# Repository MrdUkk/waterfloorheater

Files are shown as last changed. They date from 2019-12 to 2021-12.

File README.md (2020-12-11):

# water floor heater system

Complete and ready-to-use WiFi-enabled water floors heating system with remote sensors and 
controllers over 1-wire (One Wire) interface.

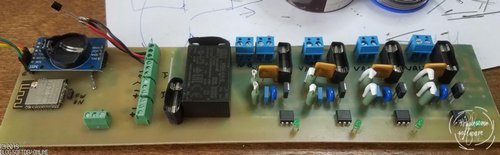
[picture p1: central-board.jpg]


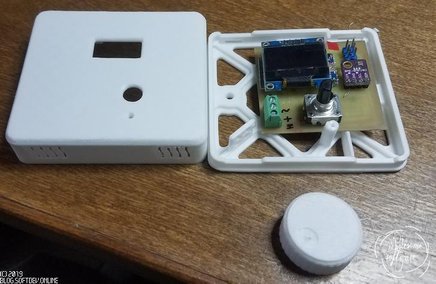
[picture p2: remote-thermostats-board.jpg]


Uses: 
1. OLED 0.96" display (no-name China), 
2. ESP32 (as central controller),
3. ATMEGA328 (as slave remote thermostats placed on rooms walls).
4. BME280 sensors
5. TRIACs (for opening/closing water valve actuators)

Full assembly instructions with photos and detailed description (written currently into Russian lang):
Part1 (hardware): https://blog.softdev.online/index.php?controller=post&action=view&id_post=10

Part2 (software): https://blog.softdev.online/index.php?controller=post&action=view&id_post=11

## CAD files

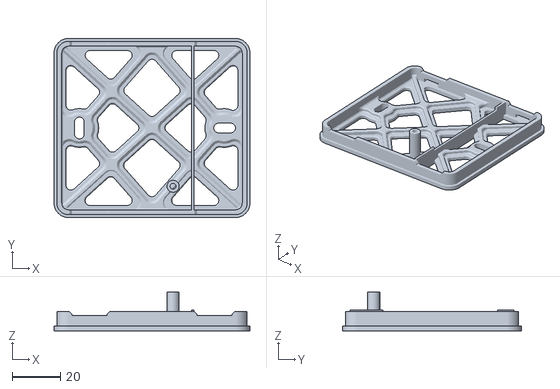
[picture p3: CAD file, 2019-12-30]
3d-shell/bottom.stl
81.0 x 74.0 x 16.0

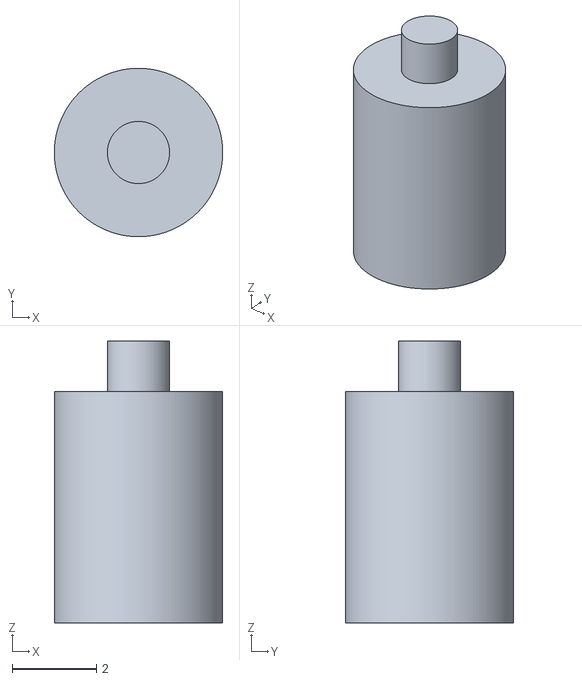
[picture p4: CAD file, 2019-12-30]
3d-shell/display-legs.stl
4.00 x 4.00 x 6.70

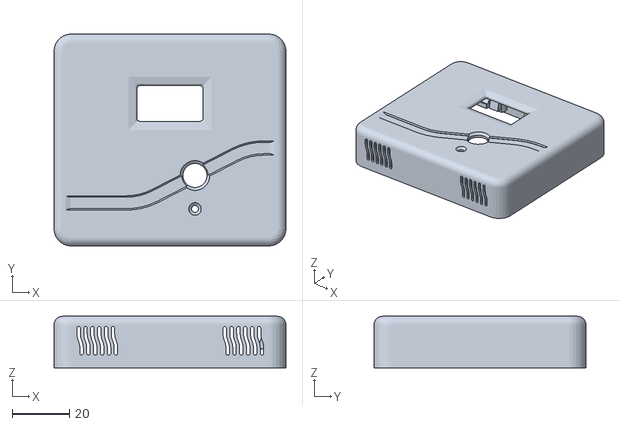
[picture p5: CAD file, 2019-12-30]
3d-shell/top.stl
81.0 x 74.0 x 18.0

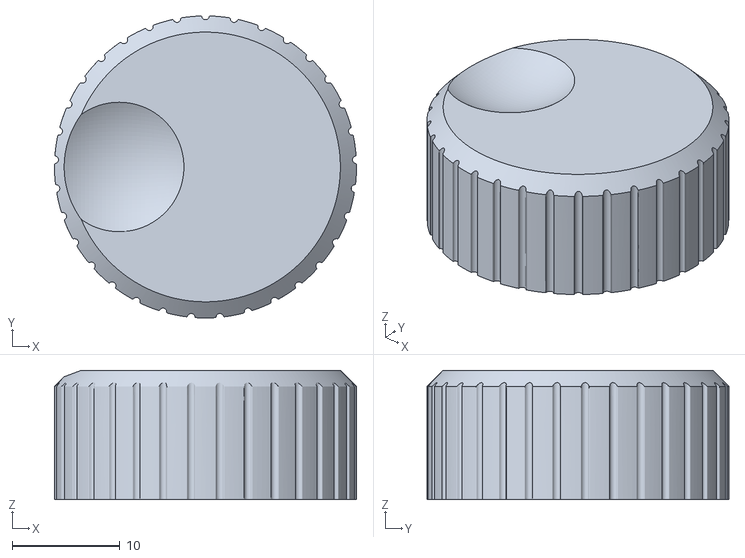
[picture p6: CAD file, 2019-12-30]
3d-shell/jog.stl
28.0 x 28.0 x 12.0

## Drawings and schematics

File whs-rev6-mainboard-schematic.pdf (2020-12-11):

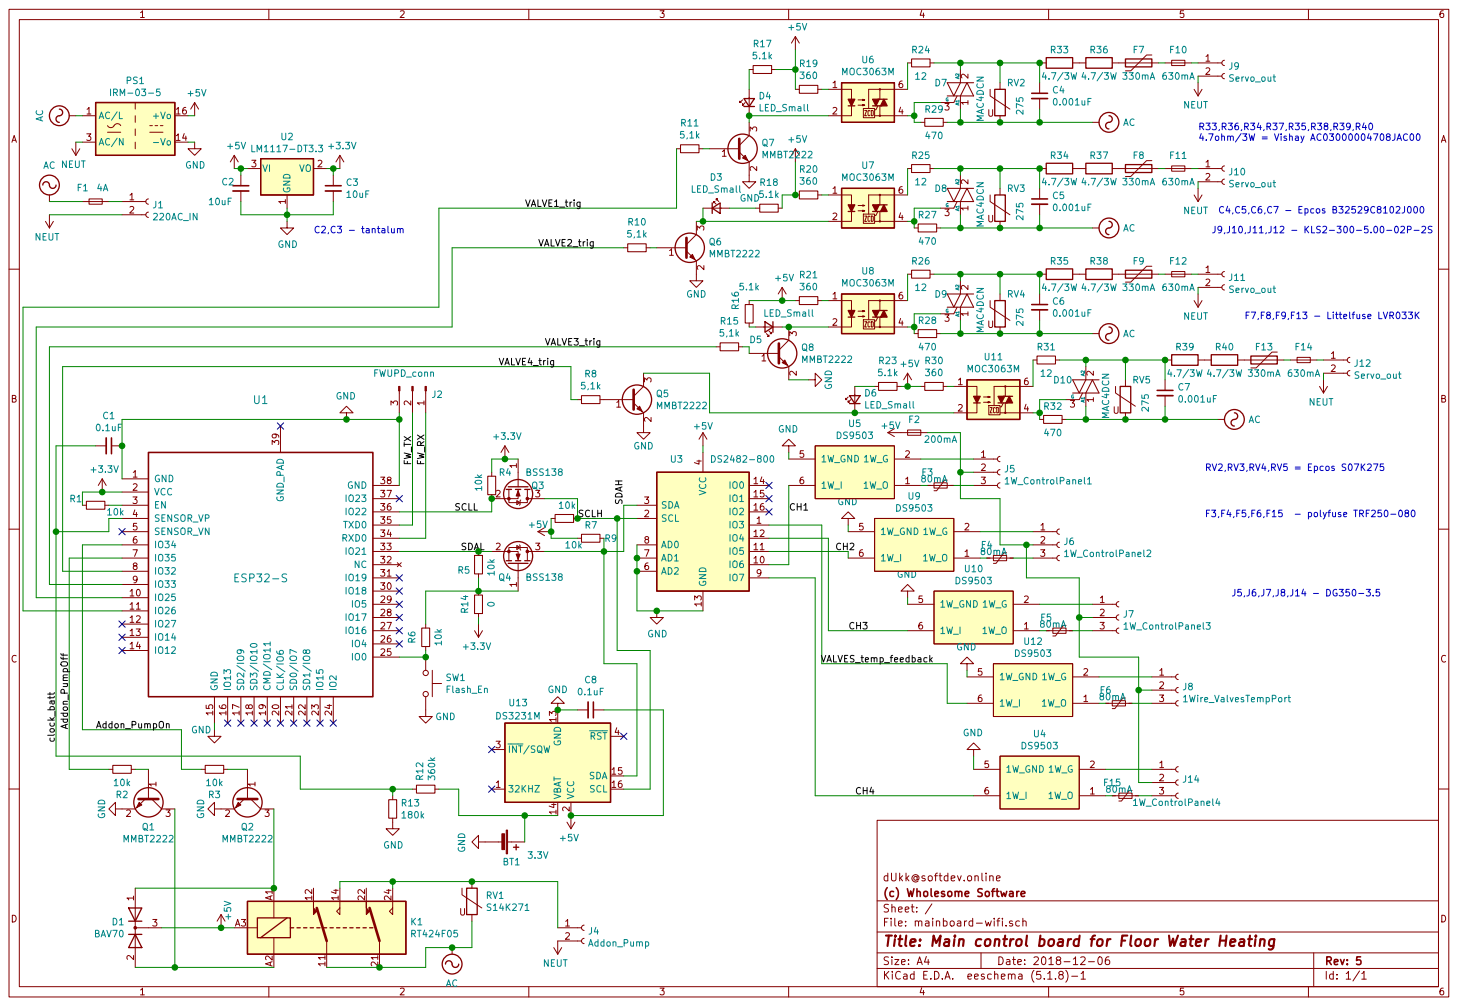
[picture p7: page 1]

File: mainboard-wifi.sch Sheet: / (c) Wholesome Software

Id: 1/1 Title: Main control board for Floor Water Heating

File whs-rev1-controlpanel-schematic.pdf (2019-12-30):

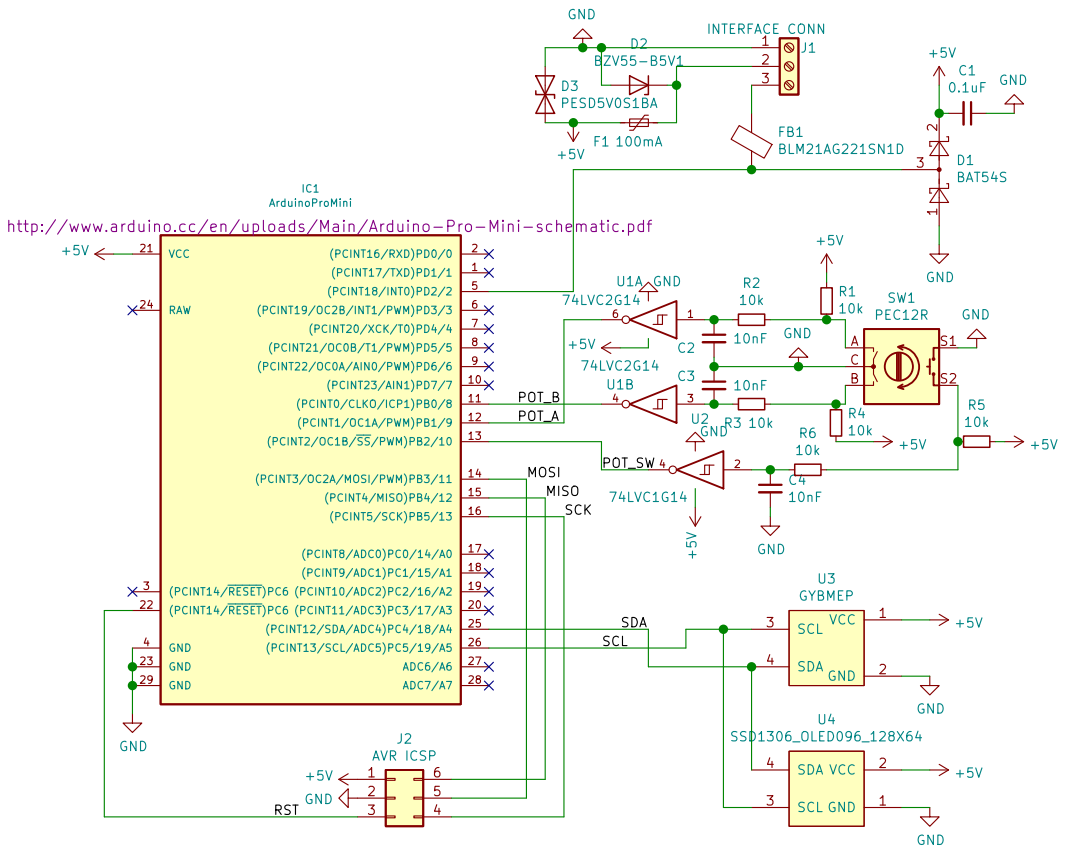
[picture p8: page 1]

File: controlpanel.sch Sheet: / Wholesome Software

Id: 1/1 Title: Control panel board for Smart Floor Heating

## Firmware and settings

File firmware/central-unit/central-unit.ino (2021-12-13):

/*
   Waterfloors Heating System (WHS)
   - main module firmware (ESP32-S microcontroller with DS8242 + DS3231)

  tested on: ArduinoIDE v1.8.15 + ESP32 Dev Module (CPU Freq 160mhz). SDK was v2.0.0


v2.0 (2021-12-13)
+fix bugs in DS2482 code
+introduce checking status of correct settings push to remote panels (in case of error will continue push)
+remove unneeded scratchpad read before pushing remote panel config (speedup)
+restored maintenance cycle in case valve is not used last X days
+added new heatin mode: duty cycle (cycling on->off mode every X seconds)
+added active-pullup mode by default ON on 1W bus
+fix multi-timezone temperature bug


   Written by dUkk (c) 2018-2021 Wholesome Software
*/

#include <Wire.h>
#include <EEPROM.h>
#include <WiFi.h>
#include <HTTPClient.h>
#include <rom/rtc.h>
#include <driver/rtc_io.h>
#include <driver/adc.h>
#include <RtcDS3231.h>
#include "MYDS2482.h"
#include "OWRemoteDevices.h"
#include "PIDLib.h"

#define DEBUG 1

#define RTCTS_OFFSET 946684800 //we get time from server at base year 1970, but here we counting from 2000

#define NO_ADDR_ASSIGNED 255

#define HEATER_MODE_OFF 0
#define HEATER_MODE_PIDTUNE 1
#define HEATER_MODE_PID_SINGLEZONE 2
#define HEATER_MODE_PID_MULTIZONE 3
#define HEATER_MODE_DUTYCYCLE 4

#define SSID_NAME "bssid"
#define SSID_PASSWORD "wifipassword"
#define HTTP_HOST "serverhost.name"
#define OUR_HOSTNAME "wfh"

#define RUNCYCLE_FREQ 20 //panels and sensors data grab cycle and PID compute cycle will run at this interval (in seconds)
#define VALVE_PWM_CYCLES 6 //TRIAC opening or closing valve window. VALVE_PWM_CYCLES*RUNCYCLE_FREQ (in seconds)
#define VALVE_INACTIVE_MAX_SECONDS 345600  //this is maximum valve inactive state in seconds before we start 15minutes cycle opening and closing it
#define VALVE_MAINTENANCE_SECONDS 900 //how long valve should be opened in case of its inactive state

RtcDS3231<TwoWire> Rtc(Wire);
//1wire switch instance  0 = 0x18 address
MYDS2482 OWSwitch(0);
OWRemoteDevices OneWireBus(&OWSwitch);

RTC_DATA_ATTR uint32_t nextTimeConnect, NextRunCycleTS;
bool first_time;

struct HEATER_PANEL {
  //PID coeff
  double Kp;
  double Ki;
  double Kd;
  //manual corrections of humidity and temperature
  float toffset;
  int8_t hoffset;
  //1Wire addresses for panel and associated termometr (mounted on pipe)
  int32_t PanelAddress;
  int32_t TermalSensorAddress;
  //current channel operation mode
  uint8_t CurrentMode;   //(0= OFF, 1= PID calibration, 2= single temperature every hour, 3= three time ranges distinct temperatures
  //for 3-timezones mode (individual zone ranges and temperature)
  int32_t TZoneStart[3];
  int32_t TZoneEnd[3];
  //user setted temperature. 0..2 is for multi timezone
  double TZoneDesiredTemp[3];
  //for fixed everytime tempepature
  double desiredTemp;
  //for Hysteresis type control
  uint32_t DutyCyclesMax;
};

struct {
  //for PID
  double input;
  double output;
  //forward pipe flow temperature sensor value
  float ValveTemp;
  //room humidity from remote unit
  uint8_t humidity;
  //number of
  uint32_t OnTimeCount;
  uint16_t PanelErrorsOnBus;
  uint16_t SensorErrorsOnBus;
  uint32_t PanellastOnline;
  uint32_t SensorlastOnline;
  uint32_t NumberOfCycles;
  uint32_t LastuseTS;
  //GPIO pin number of ESP32
  uint8_t Pin;
  //this holds pointer (to HEATER_PANEL[n].) to not recalculate N-times current selected temperature
  double *ptrToCurSettemp;
  //flag to send autotune calibration data to server
  bool PIDTuneReady;
  //flag to push current config to remote panel
  bool NeedPushConfig;
} RunningValues[4];

struct MY_SETTINGS {
  uint16_t crc16;
  int32_t ConnInterval;
  wifi_power_t txpower;
  char ssid[16];
  char password[32];
  HEATER_PANEL HeaterConfig[4];
} settings;

struct rtcData_WIFI {
  uint16_t crc16;   // 2 bytes
  uint8_t channel;  // 1 byte,   3 in total
  uint8_t bssid[6]; // 6 bytes,  9 in total
  uint8_t padding;  // 1 byte,  10 in total
};

RTC_DATA_ATTR rtcData_WIFI rtcData;

PID PIDHeaterMachinery[4];

unsigned int CRC16(unsigned char *buf, int len);
String extractParam(const String &authReq, const String &param);
bool is_between(const int32_t value, const int32_t rangestart, const int32_t rangeend);
void ParseServerResponse(String &payload, String &value);
uint8_t GetDeviceIndex(const int32_t HWAddress);
bool AssignProperSetTemp(uint8_t PanelIdx, uint32_t CurTime);
void SpinPIDHeatersCycle(uint32_t CurTS);
void UpdateHeatersLastuse(uint32_t TS);
bool PushToControlPanel(uint8_t PanelIdx, uint8_t deviceIdx);
void ScanOWBus();
void saveSettings();
void loadSettings();
bool InitiateWIFI();
void ShutdownWIFI();
float getVBatt();

void setup()
{
#ifdef DEBUG
  Serial.begin(115200);
  delay(10);
  Serial.printf("our settings struct size: %d , I2C: SDA=%d SCL=%d\r\n", sizeof(settings), SDA, SCL);
#endif
  EEPROM.begin(sizeof(settings));

#ifdef DEBUG
  byte error, address;
  Serial.printf("I2C init=%d\r\n",  Wire.begin(SDA, SCL));
  for(address = 1; address < 127; address++ )
  {
    Wire.beginTransmission(address);
    error = Wire.endTransmission();
    if (error == 0)
    {
      Serial.print("I2C device found at address 0x");
      if (address<16)
        Serial.print("0");
      Serial.print(address,HEX);
      Serial.println("  !");
    }
  }
#else
  Wire.begin(SDA, SCL);
#endif

  pinMode(26, OUTPUT); //GPIO26 = valve1
  pinMode(25, OUTPUT); //GPIO25 = valve2
  pinMode(33, OUTPUT); //GPIO33 = valve3
  pinMode(32, OUTPUT); //GPIO32 = valve4
  pinMode(35, OUTPUT); //GPIO35 = Pump relay off
  pinMode(34, OUTPUT); //GPIO34 = Pump relay on

  digitalWrite(26, LOW); //Initial state
  digitalWrite(25, LOW); //Initial state
  digitalWrite(33, LOW); //Initial state
  digitalWrite(32, LOW); //Initial state
  digitalWrite(35, LOW); //Initial state
  digitalWrite(34, LOW); //Initial state

  loadSettings();
  WiFi.persistent(false);
  WiFi.setAutoConnect(false);
  WiFi.setAutoReconnect(false);
  WiFi.mode(WIFI_OFF);
  btStop();

  if (!Rtc.IsDateTimeValid())
  {
#ifdef DEBUG
    Serial.print("RTC invalid TS, resetting it\n");
#endif
      RtcDateTime compiled = RtcDateTime(__DATE__, __TIME__);
      Rtc.SetDateTime(compiled);
  }

  if (!Rtc.GetIsRunning())
  {
#ifdef DEBUG
    Serial.println("RTC not running, starting\n");
#endif
    Rtc.SetIsRunning(true);
  }
#ifdef DEBUG
  else
    Serial.print("RTC already running\n");
#endif
  Rtc.Enable32kHzPin(false);
  Rtc.SetSquareWavePin(DS3231SquareWavePin_ModeNone);

#ifdef DEBUG
  Serial.printf("1W switch reset %d\n", OWSwitch.reset());
  Serial.printf("1W switch APU %d\n", OWSwitch.configure(DS2482_CONFIG_APU));
#else
  OWSwitch.reset();
  OWSwitch.configure(DS2482_CONFIG_APU);
#endif

  //wait until all remote control panels is booted up
  //while we are waiting -> illuminate valve control LEDs for one second
  digitalWrite(26, HIGH);
  delay(1000);
  digitalWrite(26, LOW);
  digitalWrite(25, HIGH);
  delay(1000);
  digitalWrite(25, LOW);
  digitalWrite(33, HIGH);
  delay(1000);
  digitalWrite(33, LOW);
  digitalWrite(32, HIGH);
  delay(1000);
  digitalWrite(32, LOW);

  ScanOWBus();

  //check is all panels is online?
  for (uint8_t i = 0; i < OneWireBus.getDeviceCount(); i++)
  {
    //if panel is online -> light up its LED
    uint8_t idx = GetDeviceIndex(OneWireBus.getDeviceHWAddress(i));
    if(idx == NO_ADDR_ASSIGNED) continue;
    if (settings.HeaterConfig[idx].PanelAddress != 0 &&
        settings.HeaterConfig[idx].PanelAddress == OneWireBus.getDeviceHWAddress(i))
      digitalWrite(RunningValues[idx].Pin, HIGH);
  }
  delay(5000);

  nextTimeConnect = 0;
  NextRunCycleTS = 0;
  first_time = true;
}

void loop()
{
  RtcDateTime dt = Rtc.GetDateTime();

  if (dt.TotalSeconds() >= NextRunCycleTS)
  {
#ifdef DEBUG
    char datestring[20];
    snprintf_P(datestring, 20, PSTR("%02u/%02u/%04u %02u:%02u:%02u\r\n"),  dt.Month(), dt.Day(), dt.Year(), dt.Hour(), dt.Minute(), dt.Second());
    Serial.print(datestring);
#endif

    //sensors and panels data accqusion may consume more than RUNCYCLE_FREQ seconds. so we must calculate next real delay to call Run cycle monotonically
    NextRunCycleTS = dt.TotalSeconds() + RUNCYCLE_FREQ;
#ifdef DEBUG
    Serial.printf("NextRunCycleTS=%d\r\n", NextRunCycleTS);
#endif

    uint32_t SecondsSinceZZ = (dt.Hour() * 60 * 60) + (dt.Minute() * 60);

    //search again if no devices found
    if (OneWireBus.getDeviceCount() == 0)
    {
      ScanOWBus();
      delay(750); //need because sensors took some time to prepare readings
    }

    //consume data from remote sensors and panels
    ControlPanelData data;
    for (uint8_t i = 0; i < OneWireBus.getDeviceCount(); i++)
    {
      //map this sensor to our internal idx
      uint8_t idx = GetDeviceIndex(OneWireBus.getDeviceHWAddress(i));
#ifdef DEBUG
      Serial.printf("our panel ID at %d for slave %d\r\n", idx, i);
#endif
      if (idx == NO_ADDR_ASSIGNED) continue; //skip if not found

      if (OneWireBus.getDeviceType(i) == OURMODEL)
      {
        //do we need change current SetTemp assigned variable by Time constraints? (preserve current PUSH status!)
        if(AssignProperSetTemp(idx, SecondsSinceZZ)) RunningValues[idx].NeedPushConfig=true;

        //check is we need to refresh its settings?
        if(RunningValues[idx].NeedPushConfig)
        {
            if(PushToControlPanel(idx, i))
            {
#ifdef DEBUG
              Serial.printf("CONFIG PUSH success\r\n");
#endif
              RunningValues[idx].NeedPushConfig=false;
            }
#ifdef DEBUG
            else {
              Serial.printf("CONFIG PUSH ERROR!\r\n");
            }
#endif
            //delay next operation because panel needs some time to do work (write config values and retrieve sensor readings)
            delay(150);
        }

        //next is obtain values
        if (OneWireBus.GetPanelData(i, &data))
        {
#ifdef DEBUG
          Serial.printf(" slave #%d (addr: %d), returned CurrentTemp:%f, SetTemp:%f, Humidity:%d, Mode:%d, TOffset:%f\r\n", i, OneWireBus.getDeviceHWAddress(i), data.CurTemp, data.ReqTemp, data.CurHumidity, data.CurMode, data.toffset);
#endif
          //ignore readed settings if we failed push FRESH server settings to panel
          if(!RunningValues[idx].NeedPushConfig)
          {
              settings.HeaterConfig[idx].toffset = data.toffset;
              //settings.HeaterConfig[idx].hoffset
              //if remote mode is changed
              if (data.CurMode != settings.HeaterConfig[idx].CurrentMode)
              {
    #ifdef DEBUG
                Serial.printf("panel %d changed MODE via panel\r\n", i);
    #endif
                settings.HeaterConfig[idx].CurrentMode = data.CurMode;
                //for PID or AUTOTUNE -> initialize it
                if (settings.HeaterConfig[idx].CurrentMode == HEATER_MODE_PIDTUNE)
                  PIDHeaterMachinery[idx].ATCancel();
                else if (settings.HeaterConfig[idx].CurrentMode >= HEATER_MODE_PID_SINGLEZONE && settings.HeaterConfig[idx].CurrentMode <= HEATER_MODE_PID_MULTIZONE)
                {
                  PIDHeaterMachinery[idx].Reset();
                  PIDHeaterMachinery[idx].SetMode(AUTOMATIC);
                }
                else if(settings.HeaterConfig[idx].CurrentMode == HEATER_MODE_DUTYCYCLE)
                {
                  RunningValues[idx].NumberOfCycles = 1;
                }
                AssignProperSetTemp(idx, SecondsSinceZZ);
              }
              *RunningValues[idx].ptrToCurSettemp = data.ReqTemp;  //save SetTemp to CURRENT selected variable
          }
#ifdef DEBUG
          else
          {
            Serial.printf(" slave panel #%d (addr: %d) is in push-settings state, ignored its data\r\n", i, OneWireBus.getDeviceHWAddress(i));
          }
#endif
          //anyway sensor readings is fine
          RunningValues[idx].input = data.CurTemp;
          RunningValues[idx].humidity = data.CurHumidity;
          RunningValues[idx].PanellastOnline = dt.TotalSeconds();
          RunningValues[idx].PanelErrorsOnBus = OneWireBus.getDeviceErrorsCount(i);
#ifdef DEBUG
          Serial.printf(" slave panel #%d (addr: %d) processed telemetry\r\n", i, OneWireBus.getDeviceHWAddress(i));
#endif
        }
        else
        {
          RunningValues[idx].PanelErrorsOnBus = OneWireBus.getDeviceErrorsCount(i);
#ifdef DEBUG
          Serial.printf(" slave panel #%d (addr: %d), not responding! Errors counter=%d\r\n", i, OneWireBus.getDeviceHWAddress(i), RunningValues[idx].PanelErrorsOnBus);
#endif
        }
      }
      else
      {
        if (OneWireBus.getDSTemperature(i, &RunningValues[idx].ValveTemp))
        {
#ifdef DEBUG
          Serial.printf(" slave #%d SensorTemp=%f\r\n", i, RunningValues[idx].ValveTemp);
#endif
          RunningValues[idx].SensorlastOnline = dt.TotalSeconds();
          RunningValues[idx].SensorErrorsOnBus = OneWireBus.getDeviceErrorsCount(i);
        }
        else
        {
          RunningValues[idx].SensorErrorsOnBus = OneWireBus.getDeviceErrorsCount(i);
#ifdef DEBUG
          Serial.printf(" slave sensor #%d (addr: %d), not responding! Errors counter=%d\r\n", i, OneWireBus.getDeviceHWAddress(i), RunningValues[idx].SensorErrorsOnBus);
#endif
        }
      }

      //
#ifdef DEBUG
      Serial.printf(" slave #%d (addr: %d), requesting next measurement. status=%d\r\n", i, OneWireBus.getDeviceHWAddress(i), OneWireBus.requestDataMetering(i));
#else
      OneWireBus.requestDataMetering(i);
#endif
    }

    //now spinup PID cycles
    SpinPIDHeatersCycle(dt.TotalSeconds());
  }

  //check is we need to connect with server?
  if (dt.TotalSeconds() >= nextTimeConnect)
  {
#ifdef DEBUG
    Serial.printf("curts=%d , %d seconds elapsed, time to connect to server (next %d)\r\n", dt.TotalSeconds(), settings.ConnInterval, nextTimeConnect);
#endif

    //here we see is in elapsed time interval heater is ON sometime
    UpdateHeatersLastuse(dt.TotalSeconds());

    if (InitiateWIFI())
    {
      HTTPClient http;
      String value;
      value.concat(F("/senshandle.php?hid="));
      value.concat(WiFi.getHostname());
      if (first_time)
      {
        value += "&boot=";
        value.concat((int)rtc_get_reset_reason(0));
      }
      http.begin(F(HTTP_HOST), 80, value);
      http.addHeader("Content-Type", "application/octet-stream");
      //serialize data to XML
      value = "<settings vbatt=\"";
      value.concat(getVBatt());
      value += "\" itemp=\"";
      value.concat(Rtc.GetTemperature().AsFloatDegC());
      value += "\">";
      for (uint8_t i = 0; i < 4; i++)
      {
        value += "<heater id=\"";
        value.concat(i);
        value += "\" paneladdr=\"";
        value.concat(settings.HeaterConfig[i].PanelAddress);
        value += "\" tempsensaddr=\"";
        value.concat(settings.HeaterConfig[i].TermalSensorAddress);
        value += "\" mode=\"";
        value.concat(settings.HeaterConfig[i].CurrentMode);
        value += "\" settemp=\"";
        value.concat(*RunningValues[i].ptrToCurSettemp);
        value += "\" curtemp=\"";
        value.concat(RunningValues[i].input);
        value += "\" toff=\"";
        value.concat(settings.HeaterConfig[i].toffset);
        value += "\" hoff=\"";
        value.concat(settings.HeaterConfig[i].hoffset);
        value += "\" valvetemp=\"";
        value.concat(RunningValues[i].ValveTemp);
        value += "\" humidity=\"";
        value.concat(RunningValues[i].humidity);
        value += "\" sensorerrors=\"";
        value.concat(RunningValues[i].SensorErrorsOnBus);
        value += "\" panelerrors=\"";
        value.concat(RunningValues[i].PanelErrorsOnBus);
        value += "\" oncounter=\"";
        value.concat(RunningValues[i].OnTimeCount);
        value += "\" slastseen=\"";
        if (RunningValues[i].SensorlastOnline == 0) value.concat(0);
        else value.concat(RunningValues[i].SensorlastOnline + RTCTS_OFFSET);
        value += "\" plastseen=\"";
        if (RunningValues[i].PanellastOnline == 0) value.concat(0);
        else value.concat(RunningValues[i].PanellastOnline + RTCTS_OFFSET);
        if (RunningValues[i].PIDTuneReady)
        {
          RunningValues[i].PIDTuneReady = false;
          value += "\" atkp=\"";
          value.concat(PIDHeaterMachinery[i].ATGetKp());
          value += "\" atki=\"";
          value.concat(PIDHeaterMachinery[i].ATGetKi());
          value += "\" atkd=\"";
          value.concat(PIDHeaterMachinery[i].ATGetKd());
        }
        value += "\" />";

        RunningValues[i].OnTimeCount = 0;
      }
      value += "</settings>";
      int httpCode = http.POST(value);
#ifdef DEBUG
      Serial.printf("HTTP response %d\r\n", httpCode);
#endif
      if (httpCode == HTTP_CODE_OK)
      {
        if (first_time) first_time = false;
        ParseServerResponse(http.getString(), value);
      }
      //set next connect timestamp
      dt = Rtc.GetDateTime();
      nextTimeConnect = dt.TotalSeconds() + settings.ConnInterval;
    }
    //missed connect let's retry fastly
    else
    {
#ifdef DEBUG
      Serial.printf("missing WIFI connection, will retry 10seconds later\r\n");
#endif
      dt = Rtc.GetDateTime();
      nextTimeConnect = dt.TotalSeconds() + 10;
    }
    ShutdownWIFI();
  }

  //determine how much seconds we allowed to powerdown MCU?
  //either WIFI or RUN cycles come first
  int32_t seconds = 0;
#ifdef DEBUG
  Serial.printf("nextTimeConnect=%d  NextRunCycleTS=%d\r\n", nextTimeConnect, NextRunCycleTS);
#endif
  if (nextTimeConnect > NextRunCycleTS)
  {
    seconds = NextRunCycleTS - dt.TotalSeconds();
  }
  else
  {
    seconds = nextTimeConnect - dt.TotalSeconds();
  }

  if (seconds > 0)
  {
#ifdef DEBUG
    Serial.printf("allowed powerdown for %d seconds\r\n", seconds);
#endif
    esp_sleep_enable_timer_wakeup(seconds * 1000000);

#ifdef DEBUG
    for (int a = 0; a < 4; a++) Serial.printf("[%d] = %d\r\n", a, digitalRead(RunningValues[a].Pin));
#endif
    if (digitalRead(GPIO_NUM_26))
      gpio_hold_en(GPIO_NUM_26);
    if (digitalRead(GPIO_NUM_25))
      gpio_hold_en(GPIO_NUM_25);
    if (digitalRead(GPIO_NUM_33))
      gpio_hold_en(GPIO_NUM_33);
    if (digitalRead(GPIO_NUM_32))
      gpio_hold_en(GPIO_NUM_32);

    gpio_deep_sleep_hold_en();
    WiFi.mode(WIFI_OFF);

    esp_light_sleep_start();
#ifdef DEBUG
    Serial.println("waked from powerdown GPIO states:\r\n");
    for (int a = 0; a < 4; a++) Serial.printf("[%d] = %d\r\n", a, digitalRead(RunningValues[a].Pin));
#endif

    gpio_hold_dis(GPIO_NUM_26);
    gpio_hold_dis(GPIO_NUM_25);
    gpio_hold_dis(GPIO_NUM_33);
    gpio_hold_dis(GPIO_NUM_32);

#ifdef DEBUG
    Serial.println("after gpio_hold_dis\r\n");
    for (int a = 0; a < 4; a++) Serial.printf("[%d] = %d\r\n", a, digitalRead(RunningValues[a].Pin));
#endif
  }
}
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

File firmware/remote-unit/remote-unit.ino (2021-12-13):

/* 
   Waterfloors Heating System (WHS)
   - remote unit module firmware (ATMega328p microcontroller)


V1.0 (2019-11-04)
initial version

V2.0 (2021-07-09)
Sketch uses 16826 bytes (54%) of program storage space. Maximum is 30720 bytes.
Global variables use 921 bytes (44%) of dynamic memory, leaving 1127 bytes for local variables. Maximum is 2048 bytes.

V2.1 (2021-11-13)
+changed completely ICONS (16x16 -> 32x32)
+rework BME280 class (compactify, fix initialization bug, apply all settings at once)
+rework OneWireHub class (removed unused codepaths, compactify, fix small bug, minimize utilized CPU and memory resources)
+change menu polling from 100 to 150ms
+more smooth processing button press (not change screens while holding button)
+added software RESET function
+changed way sleep mode is entered (fixed bug too long sleeping)
+changed where CRC is calculated on writescratchpad 1W cmd (fixed bug not ack write)

Sketch uses 17724 bytes (57%) of program storage space. Maximum is 30720 bytes.
Global variables use 540 bytes (26%) of dynamic memory, leaving 1508 bytes for local variables. Maximum is 2048 bytes.


   Written by dUkk (c) 2018-2021 Wholesome Software
*/

#include <avr/sleep.h>
#include <avr/power.h>
#include <avr/wdt.h>
#include <EEPROM.h>
#include <U8x8lib.h>
#include "OneWireHub.h"
#include "OneWireItem.h"
#include "myBME280.h"

#define FIRMWARE_VERSION 2.1

#define encoderPinA 9  //PB1
#define encoderPinB 8  //PB0
#define encoderPinSW 10  //PB2

U8X8_SSD1306_128X64_NONAME_HW_I2C Display(U8X8_PIN_NONE); //0x3C byte addr
BME280 mySensor;  //0x76 byte addr
auto hub = OneWireHub(2); //in IDE this is 2 , on PCB this is pin 2
auto ourOWsensor = OneWireItem();

const uint8_t SymbolCurTemperature[] PROGMEM = {
0x00, 0x00, 0x00, 0x00, 0x00, 0x00, 0x00, 0x00, 0x00, 0x00, 0x00, 0x00, 0x00, 0xFC, 0x0E, 0x03,
0x03, 0x0E, 0xFC, 0x00, 0x00, 0x00, 0x00, 0x00, 0x00, 0x00, 0x00, 0x00, 0x00, 0x00, 0x00, 0x00,
0x00, 0x00, 0x00, 0x00, 0x00, 0x00, 0x00, 0x00, 0x00, 0x00, 0x00, 0x00, 0x00, 0xFF, 0x00, 0x00,
0x00, 0x00, 0xFF, 0x00, 0x00, 0x00, 0x00, 0x00, 0x00, 0x00, 0x00, 0x00, 0x00, 0x00, 0x00, 0x00,
0x00, 0x00, 0x00, 0x00, 0x00, 0x00, 0x00, 0x00, 0x00, 0x00, 0xE0, 0x38, 0x0C, 0xCF, 0xE0, 0xE0,
0xE0, 0xE0, 0xCF, 0x0C, 0x18, 0xE0, 0x80, 0x00, 0x00, 0x00, 0x00, 0x00, 0x00, 0x00, 0x00, 0x00,
0x00, 0x00, 0x00, 0x00, 0x00, 0x00, 0x00, 0x00, 0x00, 0x01, 0x07, 0x1C, 0x30, 0x31, 0x23, 0x67,
0x67, 0x63, 0x33, 0x30, 0x1C, 0x0F, 0x01, 0x00, 0x00, 0x00, 0x00, 0x00, 0x00, 0x00, 0x00, 0x00
};
const uint8_t SymbolCurHumidity[] PROGMEM = {
0x00, 0x00, 0x00, 0x00, 0x00, 0x00, 0x00, 0x00, 0x00, 0x00, 0x00, 0x00, 0xC0, 0xE0, 0xF0, 0xF8,
0xF0, 0xE0, 0xC0, 0x00, 0x00, 0x00, 0x00, 0x00, 0x00, 0x00, 0x00, 0x00, 0x00, 0x00, 0x00, 0x00,
0x00, 0x00, 0x00, 0x00, 0x00, 0x00, 0x00, 0xE0, 0x20, 0x04, 0x06, 0xC7, 0x07, 0x07, 0x1F, 0xFF,
0x3F, 0x07, 0x07, 0xC3, 0xF2, 0xFC, 0xF8, 0xE0, 0x80, 0x00, 0x00, 0x00, 0x00, 0x00, 0x00, 0x00,
0x00, 0x00, 0x00, 0x00, 0x00, 0x00, 0x3E, 0xFF, 0xFE, 0xF8, 0xF8, 0xF1, 0x78, 0x08, 0x04, 0xC0,
0xE0, 0x04, 0x03, 0x03, 0x61, 0x03, 0x03, 0x07, 0xFF, 0x00, 0x00, 0x00, 0x00, 0x00, 0x00, 0x00,
0x00, 0x00, 0x00, 0x00, 0x00, 0x00, 0x00, 0x01, 0x01, 0x07, 0x0F, 0x0D, 0x1C, 0x1C, 0x1E, 0x1F,
0x1F, 0x1F, 0x1C, 0x0C, 0x0C, 0x04, 0x04, 0x01, 0x00, 0x00, 0x00, 0x00, 0x00, 0x00, 0x00, 0x00  
};
const uint8_t SymbolTempSet[] PROGMEM = {
0x00, 0x00, 0x00, 0x00, 0x00, 0x00, 0xC0, 0x80, 0x00, 0x00, 0x00, 0x00, 0x00, 0x00, 0x00, 0x34,
0x3C, 0x00, 0x00, 0x00, 0x00, 0x00, 0x00, 0x00, 0x80, 0xC0, 0x00, 0x00, 0x00, 0x00, 0x00, 0x00,
0x00, 0x00, 0x00, 0x00, 0x00, 0x00, 0x00, 0x01, 0x01, 0xC0, 0xF0, 0x18, 0x0C, 0x0C, 0x04, 0x06,
0x06, 0x04, 0x0C, 0x0C, 0x18, 0xF0, 0xC0, 0x01, 0x01, 0x00, 0x00, 0x00, 0x00, 0x00, 0x00, 0x00,
0x00, 0x01, 0x01, 0x01, 0x01, 0x01, 0x00, 0x00, 0x00, 0x71, 0xD8, 0x88, 0x00, 0x00, 0x00, 0xF8,
0xC8, 0x00, 0x00, 0x00, 0xF8, 0xD8, 0x09, 0x00, 0x00, 0x00, 0x01, 0x01, 0x01, 0x01, 0x00, 0x00,
0x00, 0x00, 0x00, 0x00, 0x00, 0x00, 0x00, 0x00, 0x00, 0x00, 0x00, 0x19, 0x1F, 0x00, 0x00, 0x00,
0x11, 0x1F, 0x06, 0x00, 0x00, 0x11, 0x1F, 0x06, 0x00, 0x00, 0x00, 0x00, 0x00, 0x00, 0x00, 0x00
};
const uint8_t SymbolModeSet[] PROGMEM = {
0x00, 0x00, 0x00, 0x00, 0x00, 0x00, 0x00, 0x00, 0x00, 0x40, 0x40, 0x40, 0x40, 0x40, 0x40, 0x40,
0x40, 0x40, 0x40, 0x40, 0x40, 0x40, 0x40, 0x00, 0x00, 0x00, 0x00, 0x00, 0x00, 0x00, 0x00, 0x00,
0x00, 0x00, 0x00, 0x00, 0x00, 0x00, 0x00, 0x00, 0x00, 0x00, 0x00, 0x00, 0x00, 0x08, 0x48, 0x40,
0x48, 0x40, 0x48, 0x40, 0x48, 0x40, 0x40, 0x00, 0x00, 0x00, 0x00, 0x00, 0x00, 0x00, 0x00, 0x00,
0x00, 0x00, 0x00, 0x00, 0x00, 0x00, 0x00, 0x00, 0x00, 0x00, 0x00, 0x00, 0x00, 0x00, 0x00, 0x08,
0x00, 0x01, 0x09, 0x08, 0x01, 0x00, 0x00, 0x00, 0x00, 0x00, 0x00, 0x00, 0x00, 0x00, 0x00, 0x00,
0x00, 0x00, 0x00, 0x00, 0x00, 0x00, 0x00, 0x00, 0x00, 0x00, 0x00, 0x00, 0x00, 0x01, 0x01, 0x01,
0x00, 0x00, 0x00, 0x00, 0x00, 0x00, 0x00, 0x00, 0x00, 0x00, 0x00, 0x00, 0x00, 0x00, 0x00, 0x00
};
const uint8_t SymbolTOffsetSet[] PROGMEM = {
0x00, 0x00, 0x08, 0x08, 0x08, 0x08, 0x08, 0x00, 0x00, 0x00, 0x00, 0x04, 0x00, 0xF4, 0x00, 0xE0,
0x00, 0x00, 0x00, 0x00, 0x00, 0x00, 0x00, 0x18, 0x04, 0x04, 0x00, 0xF0, 0x00, 0x00, 0x00, 0x00,
0x00, 0x00, 0x00, 0x00, 0x00, 0x10, 0x00, 0x00, 0x00, 0x00, 0x00, 0x00, 0x00, 0xFF, 0x00, 0xFF,
0x00, 0x00, 0x00, 0x00, 0x00, 0x00, 0x00, 0x00, 0x00, 0x00, 0x00, 0xFF, 0x00, 0x00, 0x00, 0x00,
0x00, 0x00, 0x08, 0x00, 0x08, 0x08, 0x08, 0x00, 0x00, 0x40, 0x00, 0x80, 0xC0, 0xFF, 0x90, 0x1F,
0x40, 0x00, 0x00, 0x00, 0x00, 0x40, 0x20, 0x00, 0x80, 0xF8, 0xC0, 0x07, 0x60, 0x00, 0x00, 0x00,
0x00, 0x00, 0x00, 0x00, 0x00, 0x00, 0x00, 0x00, 0x00, 0x04, 0x00, 0x13, 0x07, 0x07, 0x03, 0x10,
0x08, 0x00, 0x00, 0x00, 0x00, 0x04, 0x08, 0x13, 0x07, 0x07, 0x07, 0x10, 0x08, 0x00, 0x00, 0x00
};
const uint8_t SymbolBrightnessSet[] PROGMEM = {
0x00, 0x00, 0x00, 0x00, 0x00, 0x40, 0xC0, 0x80, 0x00, 0x00, 0x00, 0x00, 0x00, 0x00, 0x00, 0x3C,
0x3C, 0x00, 0x00, 0x00, 0x00, 0x00, 0x00, 0x00, 0x80, 0xC0, 0x40, 0x00, 0x00, 0x00, 0x00, 0x00,
0x00, 0x00, 0x00, 0x00, 0x00, 0x80, 0x00, 0x01, 0x01, 0xC0, 0x60, 0x18, 0x0C, 0x0C, 0x06, 0x06,
0x06, 0x06, 0x0C, 0x0C, 0x18, 0x60, 0xC0, 0x01, 0x01, 0x00, 0x00, 0x00, 0x00, 0x00, 0x00, 0x00,
0x00, 0x01, 0x01, 0x01, 0x01, 0x01, 0x00, 0x00, 0x00, 0x07, 0x0C, 0x18, 0x20, 0x40, 0x40, 0x40,
0x40, 0x40, 0x40, 0x20, 0x10, 0x0C, 0x07, 0x00, 0x00, 0x00, 0x01, 0x01, 0x01, 0x01, 0x01, 0x00,
0x00, 0x00, 0x00, 0x00, 0x00, 0x00, 0x07, 0x01, 0x01, 0x00, 0x00, 0x00, 0x00, 0x00, 0x00, 0x7C,
0x7C, 0x00, 0x00, 0x00, 0x00, 0x00, 0x00, 0x01, 0x01, 0x07, 0x00, 0x00, 0x00, 0x00, 0x00, 0x00
};
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

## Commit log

2019-12-30 initial first public version
    [bottom.stl, display-legs.stl, jog.stl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]
2020-12-11 new revision of system board. new firmwares revision 2
